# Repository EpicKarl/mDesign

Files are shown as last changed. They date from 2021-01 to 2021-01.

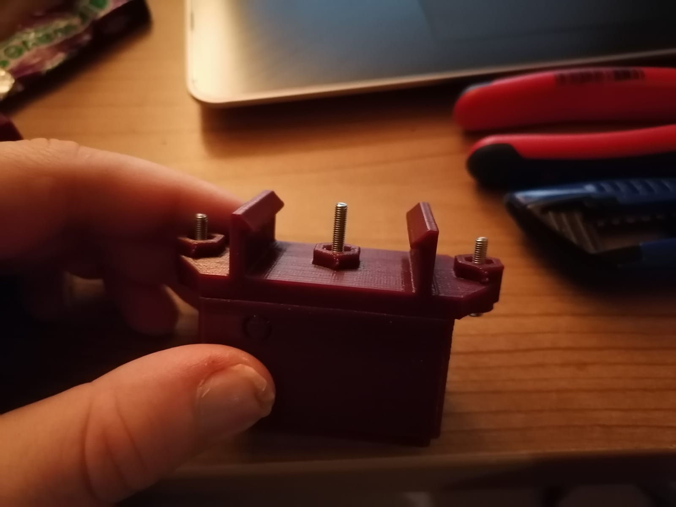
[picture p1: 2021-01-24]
Doku/HutschienengehaeuseCADDaten/ESP_Gehaeuse_Zusammenbau2.jpeg

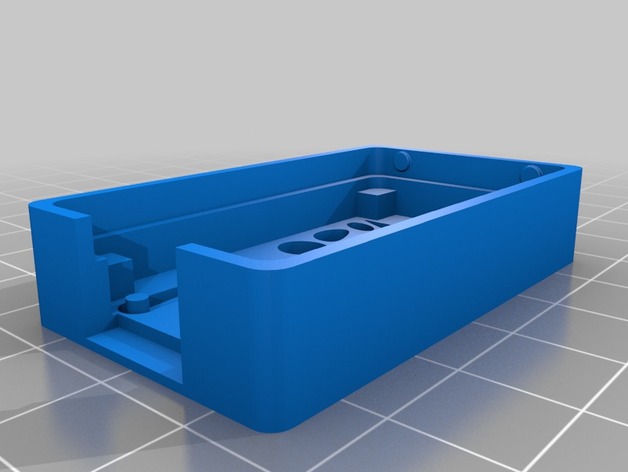
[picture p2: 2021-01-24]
Doku/HutschienengehaeuseCADDaten/ESP_Gehaeuse_Top.jpg

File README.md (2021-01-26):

# mDesign

# Aufspielen der Fernwartungsoftware auf den Node MCU ESP 8266:

1. Installiere VS Code
2. Installiere die Extension PlatformIO
3. Installiere den USB UART Treiber für den ESP 8266 aus dem Ordner "ESPDriver" oder lade ihn [hier](https://www.silabs.com/developers/usb-to-uart-bridge-vcp-drivers) herunter.
4. Workaround für die Treiberinstallation: Arduino IDE installieren

5. Clone Repository
6. VS Code starten Platform IO öffnen "Open Project" auswählen und den Ordner Fernwartung im Repo auswählen.
7. ESP mit PC verbinden
8. Bei COM Port Problemen [hier](https://docs.platformio.org/en/latest/projectconf/section_env_upload.html) nachschauen.
9. Vor dem Upload checken ob SOFTAP definiert und DEBUGMODE NICHT definiert sind.
10. Upload Button in Platform IO Project drücken. (blaue Leiste, Pfeil nach rechts)

# Debugging der Fernwartung

Für das Debuggen gibt es im Code verschiedene Präprozessoranweisungen. Dies ist nötig, da der ESP standardmäßig nur einen Hardware Serial Port besitzt. Beachte Hinweise im Code! Während ein PC an dem ESP angeschlossen ist, können dem Controllino KEINE Befehle gesendet werden.

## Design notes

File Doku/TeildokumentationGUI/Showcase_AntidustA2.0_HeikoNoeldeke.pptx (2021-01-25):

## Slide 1

- Mechatronisches Design
- Team Fernwartung
- Hochschule für Angewandte Wissenschaften Hamburg
- 26.01.2021

- V 2.0

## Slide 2

- GUI

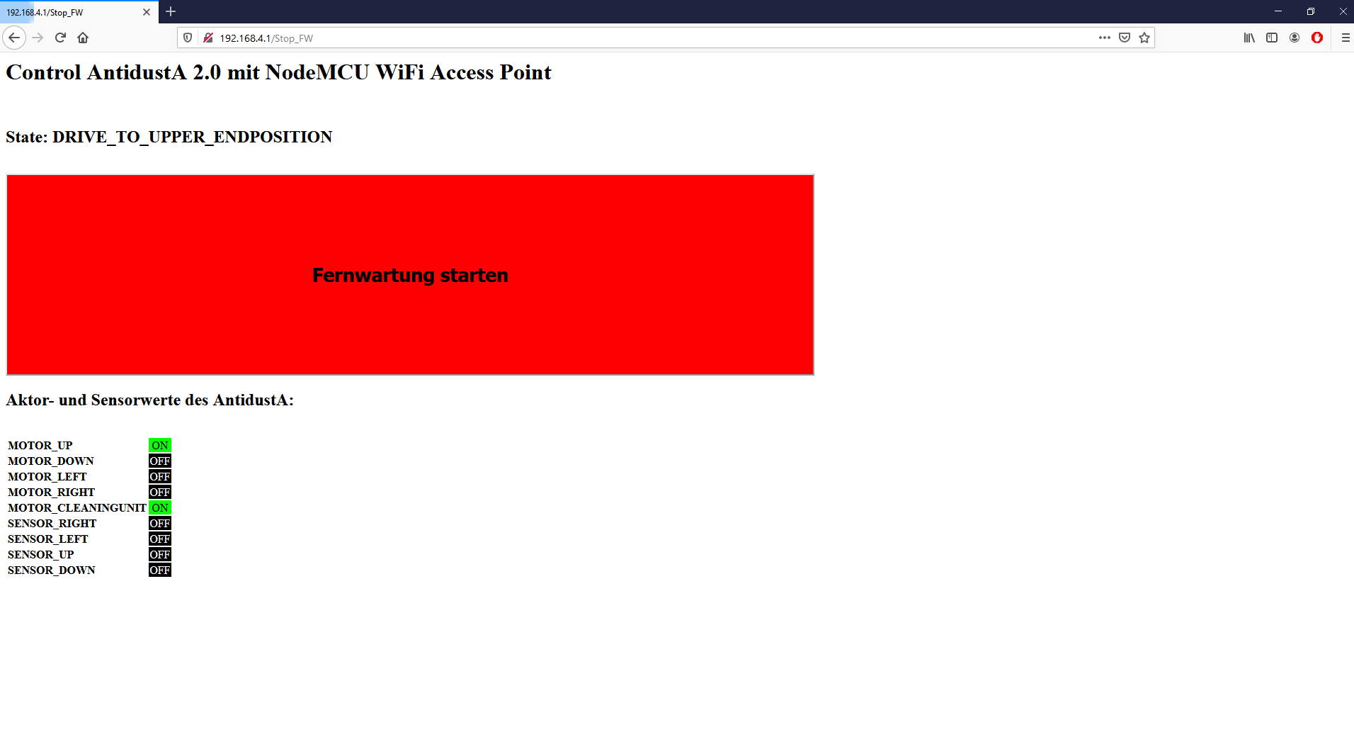
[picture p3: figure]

GUI verwenden:
- AntidustA einschalten
- Device mit WLAN „AntidustA_Control“ verbinden
- Passwort: AntidustA
- IP Adresse eingeben: 192.168.4.1
- GUI verwenden

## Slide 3

- Manueller gui Modus

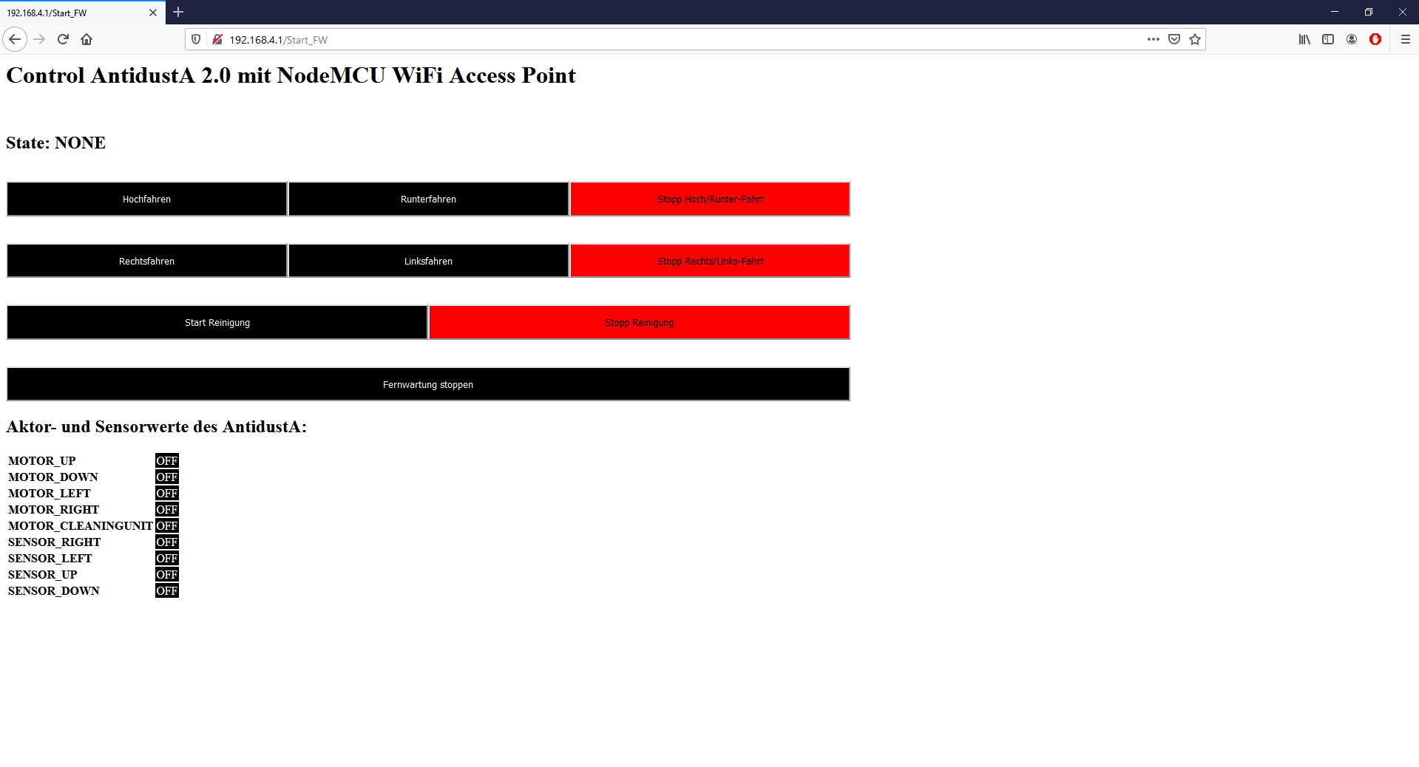
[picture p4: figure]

- Funktionalität:
- Hoch/Runter Fahrt
- Rechts/Links Fahrt
- Reinigung
- Immer nur EINE Funktionalität zeitgleich verwenden

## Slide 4

- Aktor- und sensorwerte

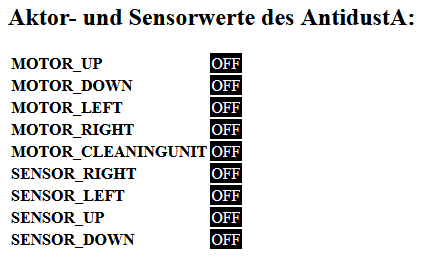
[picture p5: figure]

- Aktor- und Sensorwerte:
- Immer sichtbar
- Reagieren auf gesendete Werte vom Controllino Maxi
- Im folgenden Video: Mock-Up gibt Muster vor

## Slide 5

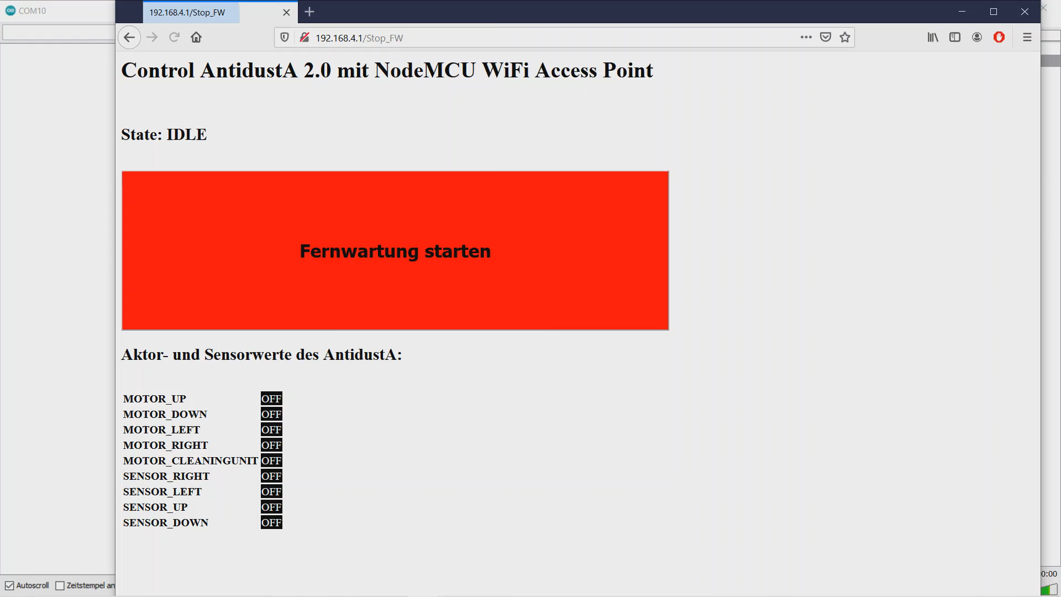
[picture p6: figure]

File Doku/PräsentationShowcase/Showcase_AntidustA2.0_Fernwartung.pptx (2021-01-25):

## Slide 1

- Mechatronisches Design
- Team Fernwartung
- Hochschule für Angewandte Wissenschaften Hamburg
- 26.01.2021

- V 2.0

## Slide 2

- Fernwartung

- Problemstellung:
- - Systeminformationen erhalten, ohne vor Ort zu sein
- - Steuerbefehle senden
- - Problemlösung aus der Ferne
- Lösung:
- - Einbau des WLAN-Moduls „NodeMCU“
- - Hosten eines Webservers auf dem Modul
- - Zugriff über Accesspoint oder bestehendes Netzwerk

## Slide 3

- Teilaufgaben

- Schnittstelle zum Controllino
- - Sensorabbild empfangen, Aktor-Abbild übertragen
- - Auswahl eines Kommunikationsprotokolls
- - Definition eines Datenrahmens
- - Codierung der Daten
- - Schreiben der Funktionen für das Empfangen der Sensor-Daten
- - Schreiben der Funktion für das Senden der Aktor-Daten
- - Entwickeln eines Testkonzepts
- Hosten des Webservers, erstellen einer GUI
- - Bereitstellen des Accesspoint/verbinden mit dem bestehenden Netzwerk
- - Hosten des Webservers
- - Entwicklung, Design und Testen der GUI
- - Verarbeitung der Nutzereingaben
- - Darstellung der Sensordaten

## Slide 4

- Schnittstelle zum Controllino - Entwurf

Wahl von UART als Kommunikationsprotokoll:

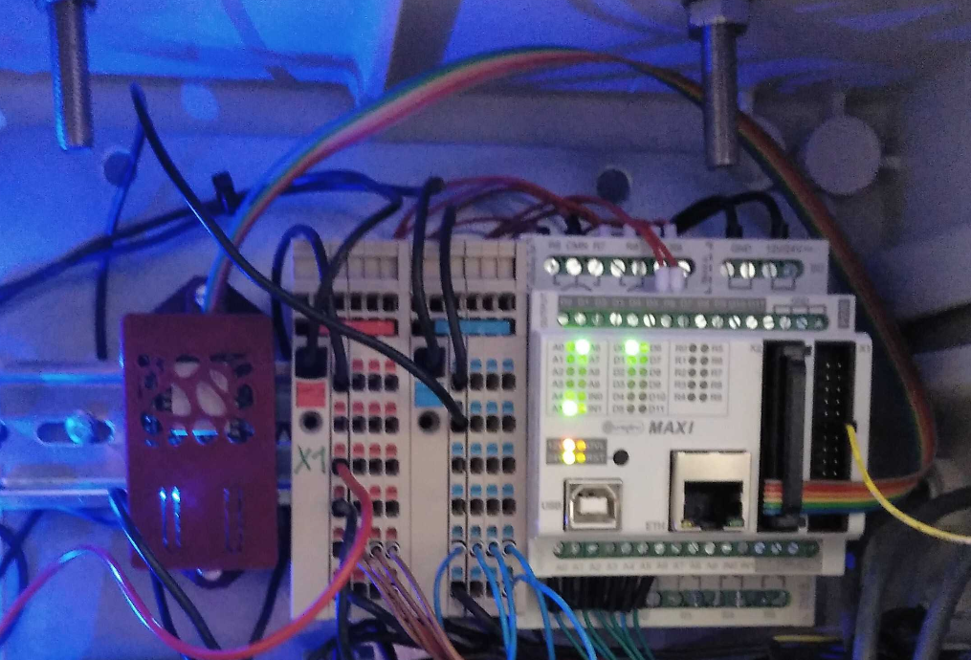
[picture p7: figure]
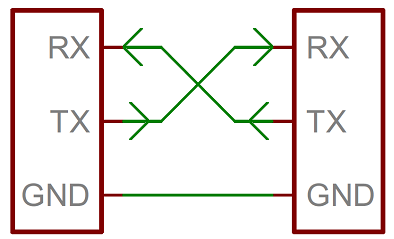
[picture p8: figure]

Telegramminhalt aus Sicht des NodeMCU:

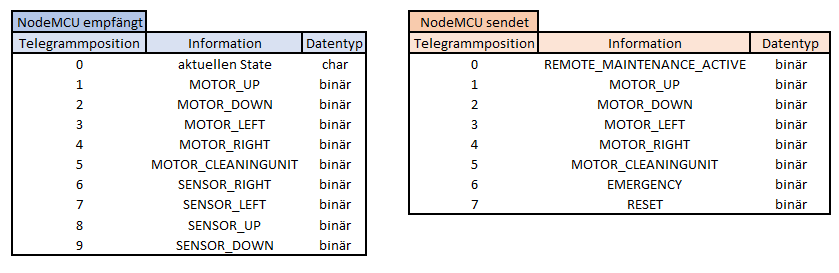
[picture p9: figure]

Codierung aller Systemzustände in Buchstaben A-L:

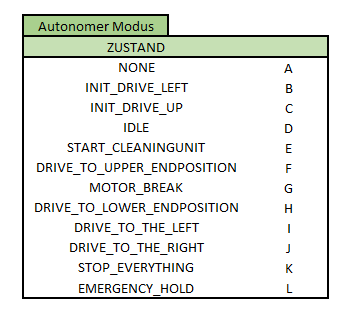
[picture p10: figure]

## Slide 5

- Schnittstelle zum Controllino - Lösungen, Test

- Funktionen für das Empfangen der Sensor-Daten
- Überprüft ob Daten zum Empfangen an der seriellen Schnittstelle anliegen
- Liest und interpretiert Daten zur weiteren Verwendung in Array ein

Funktion für das Senden der Aktor-Daten
- Sendet das im System für das Senden bereitgestellte Array an die serielle Schnittstelle

Test der Funktionen mittels Mock-Up
- Zusätzlicher Arduino simuliert das Verhalten des AntidustA während eines Reinigungsvorgangs
- Mock-Up liest Nutzereingaben aus der GUI und sendet entsprechende Reaktionen
- Das Testen der korrekten Übertagung und Interpretation der Daten wird somit ermöglicht

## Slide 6

- GUI


GUI verwenden:
- AntidustA einschalten
- Device mit WLAN „AntidustA_Control“ verbinden
- Passwort: AntidustA
- IP Adresse eingeben: 192.168.4.1
- GUI verwenden

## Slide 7

- Manueller gui Modus


- Funktionalität:
- Hoch/Runter Fahrt
- Rechts/Links Fahrt
- Reinigung
- Immer nur EINE Funktionalität zeitgleich verwenden

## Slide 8

- Aktor- und sensorwerte


- Aktor- und Sensorwerte:
- Immer sichtbar
- Reagieren auf gesendete Werte vom Controllino Maxi
- Im folgenden Video: Mock-Up gibt Muster vor

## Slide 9

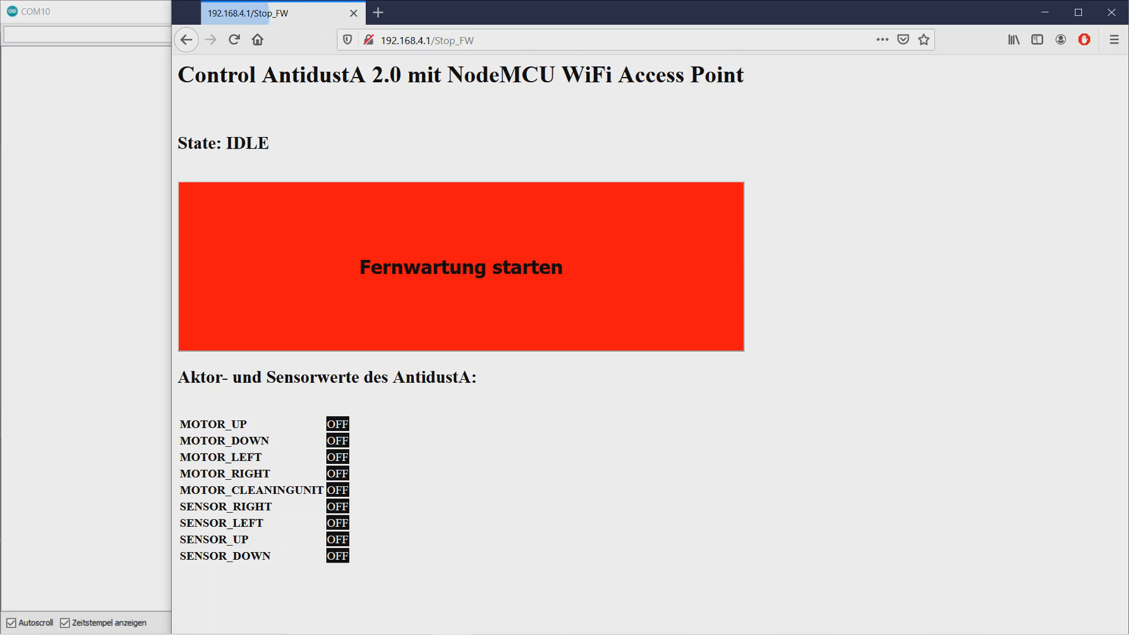
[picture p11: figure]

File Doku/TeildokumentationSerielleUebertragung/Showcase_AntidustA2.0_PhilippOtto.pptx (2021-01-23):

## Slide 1

- Mechatronisches Design
- Team X/Y
- Hochschule für Angewandte Wissenschaften Hamburg
- 26.01.2021

- V 2.0

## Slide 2

- verantwortete Systemelemente und Schnittstellen

- „Schnittstelle zum Arduino“
- Sensorabbild empfangen, Aktor-Abbild übertragen
- - Auswahl eines Kommunikationsprotokolls
- - Definition eines Datenrahmens
- - Codierung der Daten
- - Schreiben der Funktionen für das Empfangen der Sensor-Daten
- - Schreiben der Funktion für das Senden der Aktor-Daten

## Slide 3

- Entwurf – FMEA - Test

Wahl von UART als Kommunikationsprotokoll:


Telegramminhalt aus Sicht des NodeMCU:


Codierung aller Systemzustände in Buchstaben A-L:


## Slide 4

- Rückblick auf die bisherige und ausblick auf die weitere tätigkeit

- Funktionen für das Empfangen der Sensor-Daten
- Überprüft ob Daten zum Empfangen an der seriellen Schnittstelle anliegen
- Liest und interpretiert Daten zur weiteren Verwendung in Array ein

Funktion für das Senden der Aktor-Daten
- Sendet das im System für das Senden bereitgestellte Array an die serielle Schnittstelle

Test der Funktionen mittels Mock-Up
- Zusätzlicher Arduino simuliert das Verhalten des AntidustA während eines Reinigungsvorgangs
- Mock-Up liest Nutzereingaben aus der GUI und sendet entsprechende Reaktionen
- Das Testen der korrekten Übertagung und Interpretation der Daten wird somit ermöglicht

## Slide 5

- Fernwartungs-GUI

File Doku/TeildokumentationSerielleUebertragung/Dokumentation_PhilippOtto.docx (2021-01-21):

# Schnittstelle Arduino-Fernwartung

Der Datenaustausch zwischen Controllino-MAXI und NodeMCU wird mithilfe der seriellen Schnittstelle UART realisiert. Die hierfür in der Arduino-Bibliothek zur Verfügung stehenden Funktionen erleichtern die Realisierung einer solchen Übertragung.


Abbildung 1: Verschaltung zwischen Controllino-MAXI und NodeMCU

Um eine serielle Schnittstelle zwischen zwei Mikrocontrollern zu realisieren, ist es lediglich notwendig die RX und TX-Pins beider Controller gekreuzt sowie beide GND-Pins miteinander zu verbinden.

## Das Telegramm

Eine Datenübertragung erfordert ein gemeinsames Protokoll zwischen Sender und Empfänger. Da in diesem Fall Sender und Empfänger von zwei unterschiedlichen Teams bearbeitet werden ist eine gute Schnittstellen Koordination erforderlich.

Beide Seiten der Übertragung müssen auf der gleichen Baudrate kommunizieren, damit die übertragene Nachricht korrekt eingelesen werden kann.

Darüber hinaus ist es notwendig ein festen Telegramminhalt zu vereinbaren, um beim Einlesen der Nachricht eine Korrekte Interpretation der Daten durchführen zu können.

Aufgrund der statischen Interpretation der Werte ist eine konstante Länge der übertragenen Nachricht notwendig.


Abbildung 2: Übertragungsprotokoll aus Sicht des NodeMCU

Das Übertragen des aktuellen Systemzustandes stellt ein Problem dar. Systemintern wird der Zustand einem Integer Wert von 0-11 zugewiesen. Da dieser Zustand zwischen 1 und 2 Zeichen variiert, werden zu Zustande als ASCII-Zeichen anhand der gezeigten Tabelle interpretiert.


Abbildung 3: Codierung der empfangenen Zustände

Ein Ausblick auf eine mögliche Verbesserung der Übertragung wäre die Verwendung von Trennzeichen. Dadurch könnten zusammenhängende Nachrichten mit variierenden Längen besser interpretiert werden und eine fehlerhafte Übertragung wird leichter erkannt.

## Senden der Nutzereingaben

Die vom Nutzer an der GUI getätigten Eingaben werden Systemintern in einem Array aus acht Elementen gespeichert.

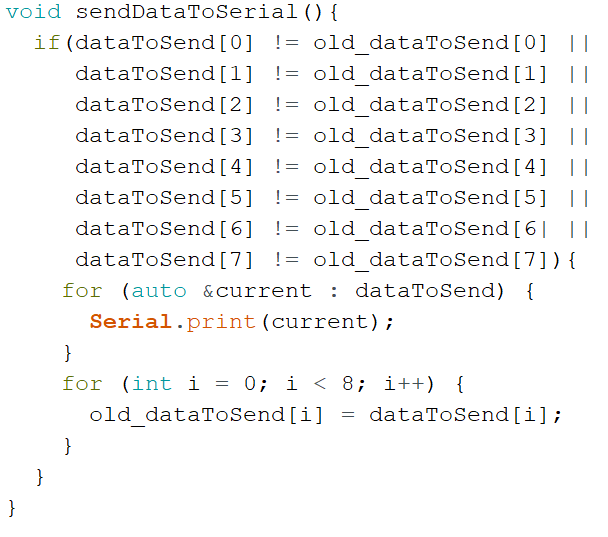
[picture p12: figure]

Abbildung 4: Funktion zur Datenübertragung an den Controllino-MAXI

Dieses Array wird nun überprüft, ob es sich im Vergleich zum letzten Systemtakt verändert hat. Ist dem der Fall, so wird durch das Array iteriert und mithilfe der Funktion Serial.print() werden die einzelnen Elemente des Arrays über den Seriellen Ausgang übertragen.

## Empfangen der Übertragung aus Controllino-MAXI

Eine Übertragung von Controllino-MAXI findet ebenfalls nur statt, wenn sich der Zustand eines der Telegrammelemente verändert. Beim Empfangen der Nachricht ist es also sinnvoll zunächst mit der Funktion Serial.available() zu überprüfen, ob auszulesende Daten am seriellen Eingang anliegen.

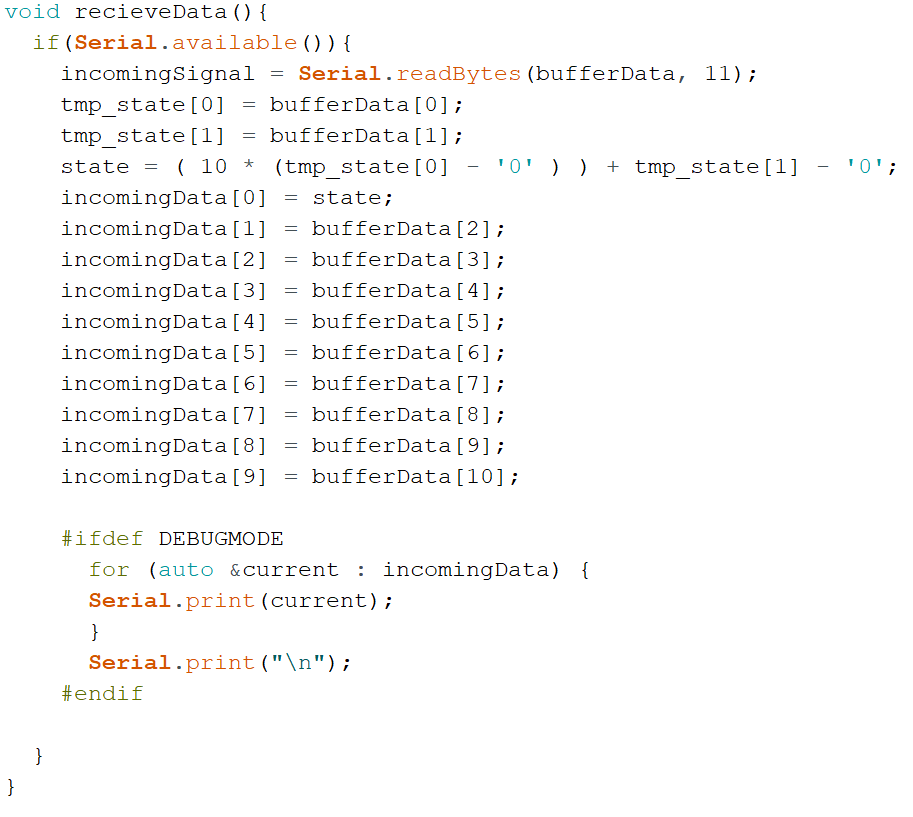
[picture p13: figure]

Abbildung 5: Funktion zum Empfangen der Daten von Controllino-MAXI

Liegen Daten am seriellen Eingang an, so werden diese zur Aufbereitung in einem Buffer gespeichert. Das erste eingelesene Element ist laut Telegrammvereinbarung immer ein Buchstabe. Dieser wird als ASCII-Zeichen übertragen. Bei der Interpretation der Empfangenen Nachricht müssen die ersten beiden Stellen des Arrays zunächst in ein Integer Wert gewandelt werden, um diesen als Char darstellen zu können.

Im Anschluss daran, können die eingelesenen Werte einem Array zugewiesen werden, welches zur weiteren Darstellung in der GUI verwendet wird.

## Testen der Funktionen

Das Testen der Funktion von GUI und Übertragung kann mithilfe eine Mock-Ups des AntidustA geschehen. Hierfür wird ein zusätzlicher Arduino verwendet, der nach einem vordefinierten Ablauf das Verhalten des AntidustA während eines Reinigungsvorgangs simuliert.

Dafür wird die Übertragene Nachricht unter Bezugnahme des Hardwareverhaltens in festgelegten Abständen variiert. In der GUI kann so der simulierte Reinigungsvorgang beobachtet werden.

Wechselt man in den manuellen Betrieb des AntidustA, so regiert der Mock-Up auf Nutzereingaben nach vorher definierten Verhaltensweisen.

Auf diese Weise kann die korrekte Funktion der GUI und das Übertragen von Daten an und von dem Controllino-MAXI getestet werden, ohne dass eine Hardware vorhanden ist.

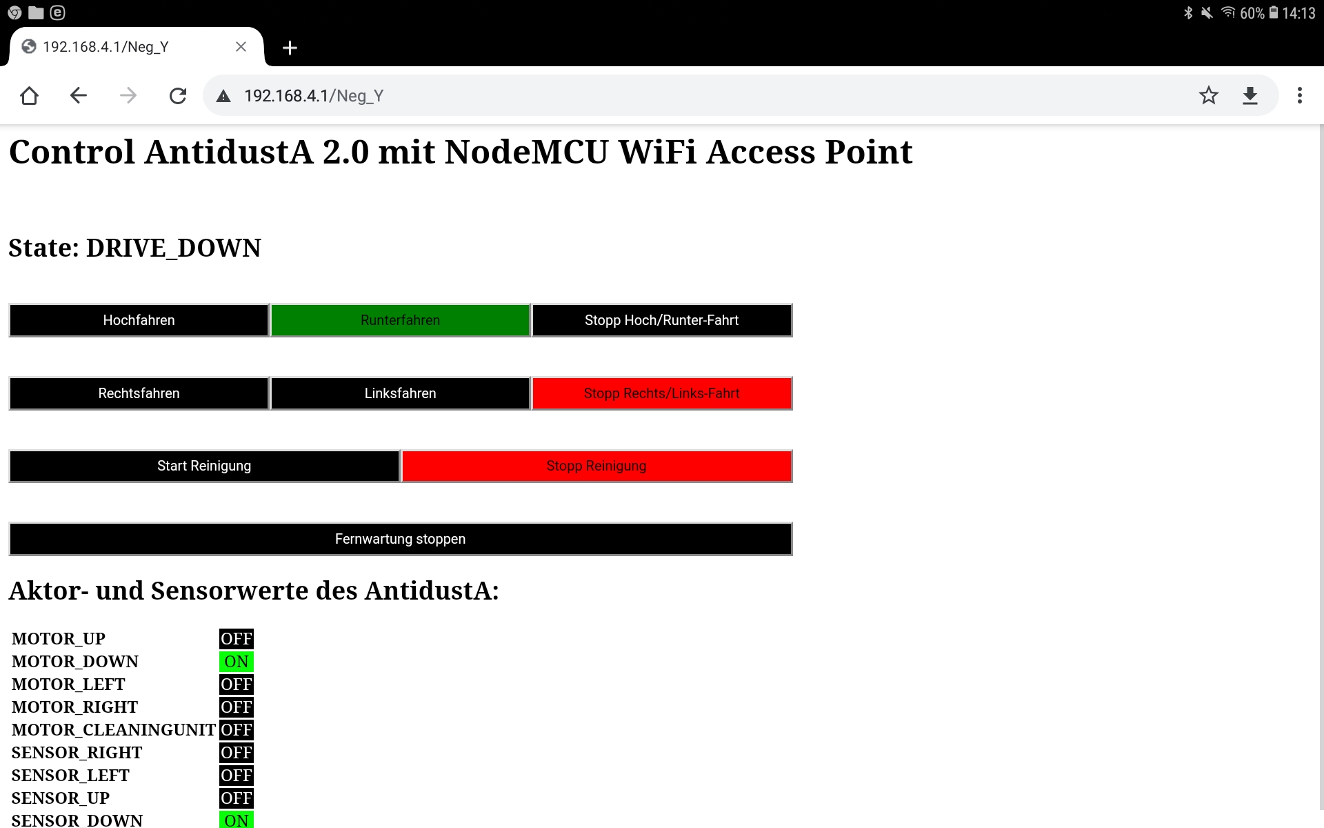
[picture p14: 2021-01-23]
Doku/TeildokumentationGUI/Bild_2.jpg

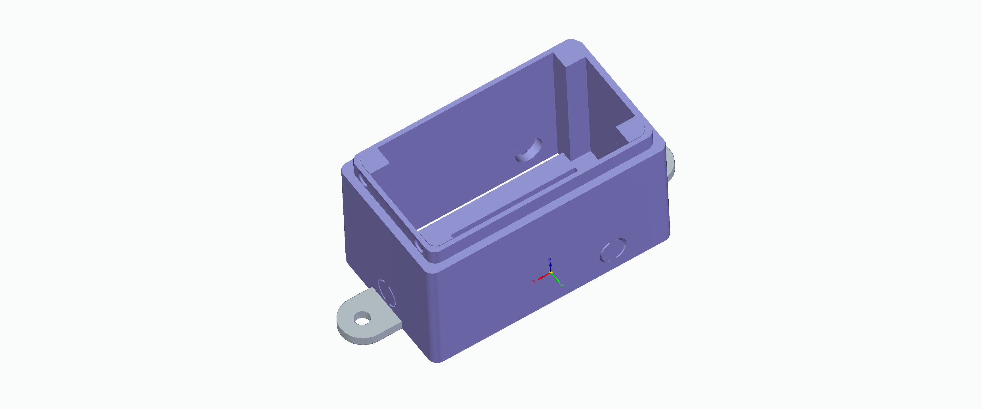
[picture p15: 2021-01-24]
Doku/HutschienengehaeuseCADDaten/ESP_BoxButtom.jpg

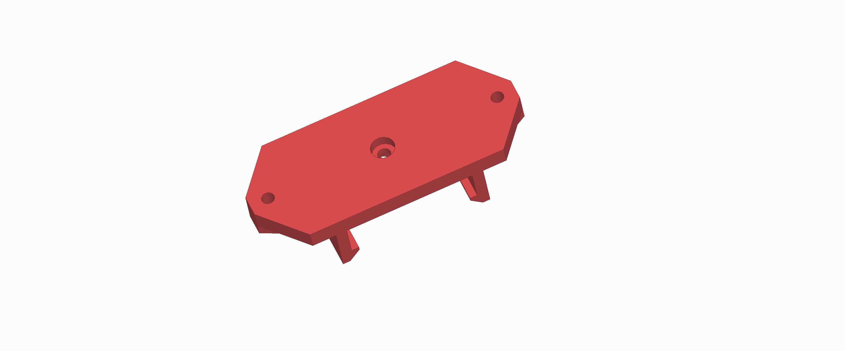
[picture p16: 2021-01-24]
Doku/HutschienengehaeuseCADDaten/ESP_AdapterBild2.jpg

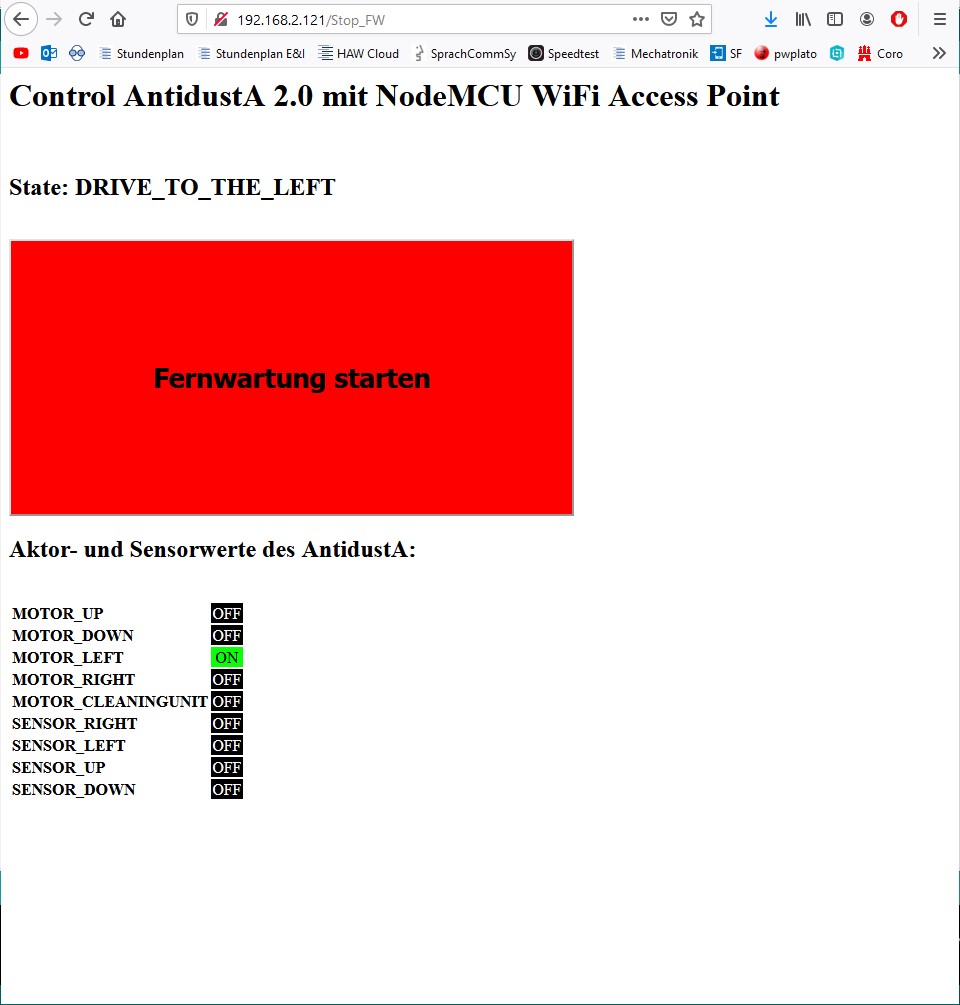
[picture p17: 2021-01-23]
Doku/TeildokumentationGUI/GUI_Automatik.jpg

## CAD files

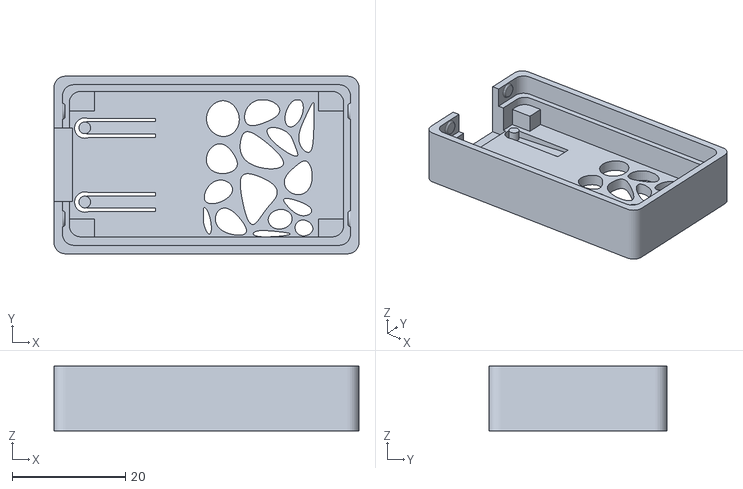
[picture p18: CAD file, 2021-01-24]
Doku/HutschienengehaeuseCADDaten/case_top_v4.stl
53.9 x 31.4 x 11.4

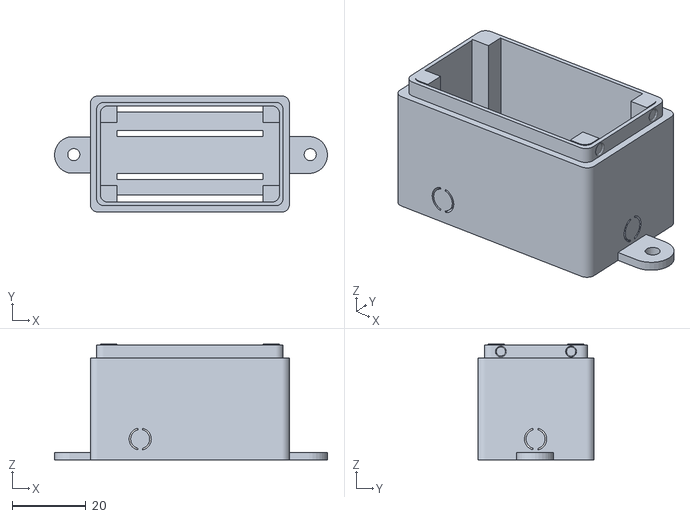
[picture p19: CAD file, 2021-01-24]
Doku/HutschienengehaeuseCADDaten/case_bottom_v3.stl
73.9 x 31.4 x 31.3

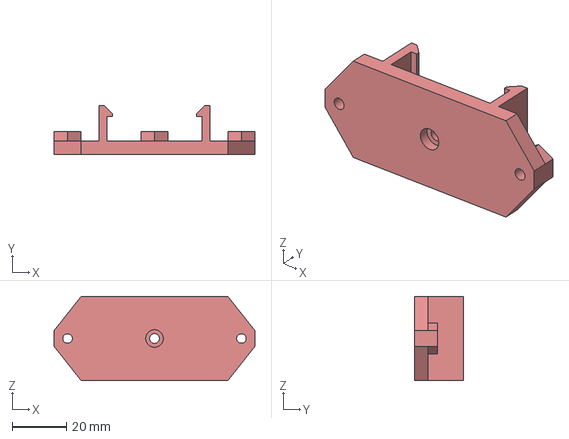
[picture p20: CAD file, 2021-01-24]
Doku/HutschienengehaeuseCADDaten/ESP_Adapter.stp
74.0 x 18.0 x 31.0 mm

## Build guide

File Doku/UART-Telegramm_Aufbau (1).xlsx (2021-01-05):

 |  |  |  | Vorschlag für zu erhaltenden Daten
Arduino Sendet |  |  |  | Arduino Empfängt
Telegrammposition | Inforamtion | Datentyp |  | Telegrammposition | Inforamtion | Datentyp
0 | aktuellen State | char |  | 0 | REMOTE_MAINTENANCE_ACTIVE | binär
1 | MOTOR_UP | binär |  | 1 | MOTOR_UP | binär
2 | MOTOR_DOWN | binär |  | 2 | MOTOR_DOWN | binär
3 | MOTOR_LEFT | binär |  | 3 | MOTOR_LEFT | binär
4 | MOTOR_RIGHT | binär |  | 4 | MOTOR_RIGHT | binär
5 | MOTOR_CLEANINGUNIT | binär |  | 5 | MOTOR_CLEANINGUNIT | binär
6 | SENSOR_RIGHT | binär |  | 6 | EMERGENCY | binär
7 | SENSOR_LEFT | binär |  | 7 | RESET | binär
8 | SENSOR_UP | binär
9 | SENSOR_DOWN | binär
MANUAL |  |  | AUTONOMOUS
ZUSTAND |  |  | ZUSTAND
NONE | A |  | NONE |  | A
DRIVE_UP | B |  | INIT_DRIVE_LEFT |  | B
DRIVE_DOWN | C |  | INIT_DRIVE_UP |  | C
DRIVE_LEFT | D |  | IDLE |  | D
DRIVE_RIGHT | E |  | START_CLEANINGUNIT |  | E
CLEANINGUNIT | F |  | DRIVE_TO_UPPER_ENDPOSITION |  | F
MOTOR_BREAK | G |  | MOTOR_BREAK |  | G
EMERGENCY_HOLD | H |  | DRIVE_TO_LOWER_ENDPOSITION |  | H
 |  |  | DRIVE_TO_THE_LEFT |  | I
 |  |  | DRIVE_TO_THE_RIGHT |  | J
 |  |  | STOP_EVERYTHING |  | K
 |  |  | EMERGENCY_HOLD |  | L

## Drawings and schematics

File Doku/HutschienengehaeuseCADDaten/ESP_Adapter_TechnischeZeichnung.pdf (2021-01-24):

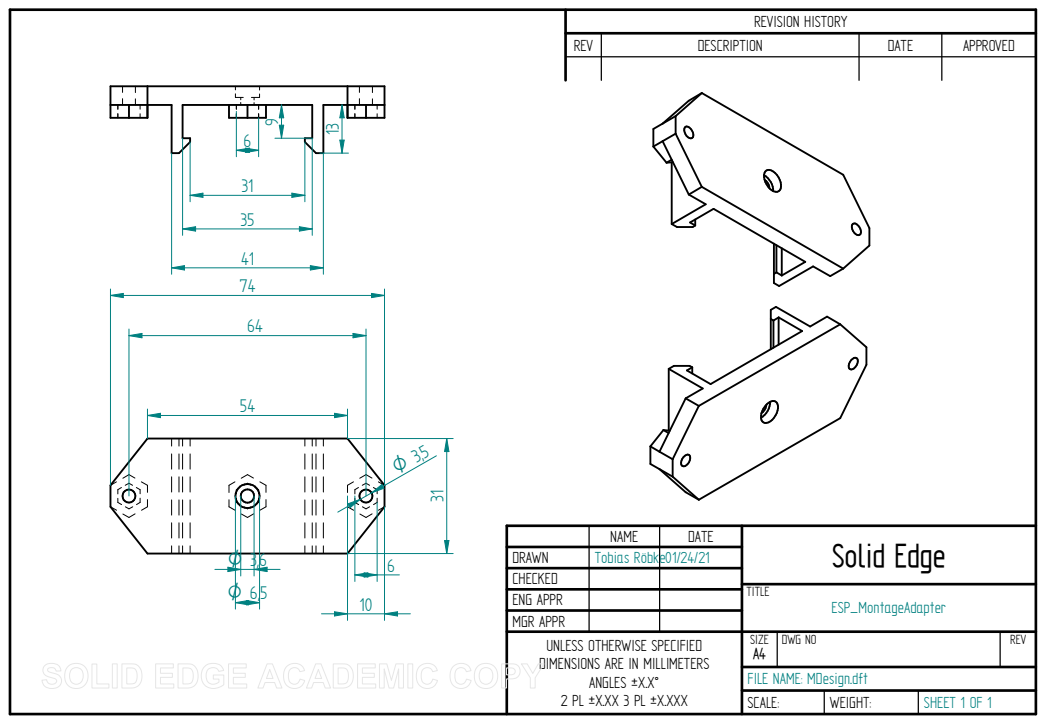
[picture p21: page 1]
TITLE; ESP_MontageAdapter; SCALE:; WEIGHT:; SHEET 1 OF 1

REVISION HISTORY

REV | DESCRIPTION | DATE | APPROVED

NAME | DATE | Solid Edge

DRAWN | Tobias Röbke | 01/24/21
CHECKED
ENG APPR
MGR APPR
UNLESS OTHERWISE SPECIFIED DIMENSIONS ARE IN MILLIMETERS ANGLES ±X.X° 2 PL ±X.XX 3 PL ±X.XXX | SIZE A4 | DWG NO | REV

FILE NAME: MDesign.dft

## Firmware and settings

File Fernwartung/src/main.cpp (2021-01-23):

// Version 1.5
/*
Ein Emergency Button aus der Ferne ist gefählich, da wir nicht sicherstellen können, dass die Verbidnung zu jeden Zeitpunkt zuverläsig ist, daher nicht zu empfehlen ---> Überarbeitung
Reset Button unnötog, wenn Emergency Button nicht implementiert
*/

//#define DEBUGMODE
//#define HOMENETWORK
#define SOFTAP

#include <Arduino.h>
#include <ESP8266WebServer.h> 
#include <ESP8266WiFi.h>
#include <WiFiClient.h>


// Receiving Data by Philipp Otto ------------------------------------------------------------------------------
byte bufferData[11] = {};
char incomingData[10] = {};

byte dataToSend[6] = {};
byte old_dataToSend[6] = {};

char tmp_state[2] = {};

byte incomingSignal;
char state;
void recieveData(){
  //Serial.setTimeout(100);
  if(Serial.available()){
    incomingSignal = Serial.readBytes(bufferData, 11);

    tmp_state[0] = bufferData[0];
    tmp_state[1] = bufferData[1];
    
    state = ( 10 * (tmp_state[0] - '0' ) ) + tmp_state[1] - '0'; // own atoi()

    incomingData[0] = state;            //Zuweisungen in char Array für Server
    incomingData[1] = bufferData[2];
    incomingData[2] = bufferData[3];
    incomingData[3] = bufferData[4];
    incomingData[4] = bufferData[5];
    incomingData[5] = bufferData[6];
    incomingData[6] = bufferData[7];
    incomingData[7] = bufferData[8];
    incomingData[8] = bufferData[9];
    incomingData[9] = bufferData[10];

    #ifdef DEBUGMODE
      for (auto &current : incomingData) {  //Konsolenausgabe zum Debuggen
      Serial.print(current);              
      }
      Serial.print("\n");
    #endif

  }
}

void sendDataToSerial(){
  if(dataToSend[0] != old_dataToSend[0] || //sendet nur wenn sich irgendwas ändert
     dataToSend[1] != old_dataToSend[1] || 
     dataToSend[2] != old_dataToSend[2] ||
     dataToSend[3] != old_dataToSend[3] ||
     dataToSend[4] != old_dataToSend[4] ||
     dataToSend[5] != old_dataToSend[5]){
    for (auto &current : dataToSend) { 
      Serial.print(current);
    }
    for (int i = 0; i < 6; i++) {
      old_dataToSend[i] = dataToSend[i];
    }
  }
}
//-------------------------------------------------------------------------------------------------------------------------------------------------------------------------------------------

//Instanz des ESP8266WebServers
ESP8266WebServer server(80);

// Make a wifi name and password as access points
#ifdef HOMENETWORK
  const char *ssid = "********";
  const char *password = "*******";
#endif
  
#ifdef SOFTAP
  const char *ssid = "AntidustA_Control";
  const char *password = "AntidustA";
#endif
// ------------------------------------Declare constants to make the page to be visited.----------------------------
/*const String HtmlHtml = "<html><head>"
"<meta name=\"viewport\" content=\"width=device-width, initial-scale=1\" /></head>";*/
const String HtmlHtml = "<html><head>"
"<meta name=\"viewport\" content=\"width=device-width, initial-scale=1\" />"
"<meta http-equiv=\"REFRESH\" content=\"1\"/>"
"</head>";
const String HtmlTitle = "<h1>Control AntidustA 2.0 mit NodeMCU WiFi Access Point</h1><br/>";
const String HtmlHtmlClose = "</html>";
// -----------------------------------------------------------------------------------------------------------------
void response(){
  String htmlRes = HtmlHtml + HtmlTitle;
  if(dataToSend[0] == 0){
    //STATE
    switch (incomingData[0])
    {
      case 'A':
        htmlRes += "<h2>State: NONE</h2><br/>";
        break;
      case 'B':
        htmlRes += "<h2>State: INIT_DRIVE_LEFT</h2><br/>";
        break;
      case 'C':
        htmlRes += "<h2>State: INIT_DRIVE_UP</h2><br/>";
        break;
      case 'D':
        htmlRes += "<h2>State: IDLE</h2><br/>";
        break;
      case 'E':
        htmlRes += "<h2>State: START_CLEANING</h2><br/>";
        break;
      case 'F':
        htmlRes += "<h2>State: DRIVE_TO_UPPER_ENDPOSITION</h2><br/>";
        break;
      case 'G':
        htmlRes += "<h2>State: MOTOR_BREAK</h2><br/>";
        break;
      case 'H':
        htmlRes += "<h2>State: DRIVE_TO_LOWER_ENDPOSITION</h2><br/>";
        break;
      case 'I':
        htmlRes += "<h2>State: DRIVE_TO_THE_LEFT</h2><br/>";
        break;
      case 'J':
        htmlRes += "<h2>State: DRIVE_TO_THE_RIGHT</h2><br/>";
        break;
      case 'K':
        htmlRes += "<h2>State: STOP_EVERYTHING</h2><br/>";
        break;
      case 'L':
        htmlRes += "<h2>State: EMERGENCY_HOLD</h2><br/>";
        break;
      default:
        htmlRes += "<h2><font style=\"color:red\">FSM IST IN KEINEM DEFINIERTEN STATE! KONTROLLE DES SYSTEMS ERFORDERLICH!</font></h2><br/>";
        break;
    }
    //Fernwarung Starten
    htmlRes += "<a href=\"Start_FW\"><button style=\"background-color:red;color:black;width:60%;height:30%;\"><h1>Fernwartung starten</h1></button></a>";
    //Aktor und Sensorwerte
    htmlRes += "<h2>Aktor- und Sensorwerte des AntidustA:</h2><br/>";
    
    htmlRes += "<table>";
    
    if(incomingData[1] == '1'){
      htmlRes += "<tr> <td> <b>MOTOR_UP</b> </td> <td style=\"background-color:#08FF08;color:#000000\"align=center>ON</td> </tr>";
    }
    if(incomingData[1] == '0'){
      htmlRes += "<tr> <td> <b>MOTOR_UP</b> </td> <td style=\"background-color:#000000;color:white;\"align=center>OFF</td> </tr>";
    }
    
    if(incomingData[2] == '1'){
      htmlRes += "<tr> <td> <b>MOTOR_DOWN</b> </td> <td style=\"background-color:#08FF08;color:#000000\"align=center>ON</td> </tr>";
    }
    if(incomingData[2] == '0'){
      htmlRes += "<tr> <td> <b>MOTOR_DOWN</b> </td> <td style=\"background-color:#000000;color:white\"align=center>OFF</td> </tr>";
    }
    
    if(incomingData[3] == '1'){
      htmlRes += "<tr> <td> <b>MOTOR_LEFT</b </td> <td style=\"background-color:#08FF08;color:#000000\"align=center>ON</td> </tr>";
    }
    if(incomingData[3] == '0'){
      htmlRes += "<tr> <td> <b>MOTOR_LEFT</b> </td> <td style=\"background-color:#000000;color:white\"align=center>OFF</td> </tr>";
    }

    if(incomingData[4] == '1'){
      htmlRes += "<tr> <td> <b>MOTOR_RIGHT</b> </td> <td style=\"background-color:#08FF08;color:#000000\"align=center>ON</td> </tr>";
    }
    if(incomingData[4] == '0'){
      htmlRes += "<tr> <td> <b>MOTOR_RIGHT</b> </td> <td style=\"background-color:#000000;color:white\"align=center>OFF</td> </tr>";
    }

    if(incomingData[5] == '1'){
      htmlRes += "<tr> <td> <b>MOTOR_CLEANINGUNIT</b> </td> <td style=\"background-color:#08FF08;color:#000000\"align=center>ON</td> </tr>";
    }
    if(incomingData[5] == '0'){
      htmlRes += "<tr> <td> <b>MOTOR_CLEANINGUNIT</b> </td> <td style=\"background-color:#000000;color:white\"align=center>OFF</td> </tr>";
    }

    if(incomingData[6] == '1'){
      htmlRes += "<tr> <td> <b>SENSOR_RIGHT</b> </td> <td style=\"background-color:#08FF08;color:#000000\"align=center>ON</td> </tr>";
    }
    if(incomingData[6] == '0'){
      htmlRes += "<tr> <td> <b>SENSOR_RIGHT</b> </td> <td style=\"background-color:#000000;color:white\"align=center>OFF</td> </tr>";
    }

    if(incomingData[7] == '1'){
      htmlRes += "<tr> <td> <b>SENSOR_LEFT</b> </td> <td style=\"background-color:#08FF08;color:#000000\"align=center>ON</td> </tr>";
    }
    if(incomingData[7] == '0'){
      htmlRes += "<tr> <td> <b>SENSOR_LEFT</b> </td> <td style=\"background-color:#000000;color:white\"align=center>OFF</td> </tr>";
    }

    if(incomingData[8] == '1'){
      htmlRes += "<tr> <td> <b>SENSOR_UP</b> </td> <td style=\"background-color:#08FF08;color:#000000\"align=center>ON</td> </tr>";
    }
    if(incomingData[8] == '0'){
      htmlRes += "<tr> <td> <b>SENSOR_UP</b> </td> <td style=\"background-color:#000000;color:white\"align=center>OFF</td> </tr>";
    }

    if(incomingData[9] == '1'){
      htmlRes += "<tr> <td> <b>SENSOR_DOWN</b> </td> <td style=\"background-color:#08FF08;color:#000000\"align=center>ON</td> </tr>";
    }
    if(incomingData[9] == '0'){
      htmlRes += "<tr> <td> <b>SENSOR_DOWN</b> </td> <td style=\"background-color:#000000;color:white\"align=center>OFF</td> </tr>";
    }

    htmlRes += "</table>";

    htmlRes += HtmlHtmlClose;
    server.send(200, "text/html", htmlRes); 
  }
  else {
    //STATE
    switch (incomingData[0])
    {
      case 'A':
        htmlRes += "<h2>State: <font color:red>NONE</font></h2><br/>";
        break;
      case 'B':
        htmlRes += "<h2>State: DRIVE_UP</h2><br/>";
        break;
      case 'C':
        htmlRes += "<h2>State: DRIVE_DOWN</h2><br/>";
        break;
      case 'D':
        htmlRes += "<h2>State: DRIVE_LEFT</h2><br/>";
        break;
      case 'E':
        htmlRes += "<h2>State: DRIVE_RIGHT</h2><br/>";
        break;
      case 'F':
        htmlRes += "<h2>State: CLEANINGUNIT</h2><br/>";
        break;
      case 'G':
        htmlRes += "<h2>State: MOTOR_BREAK</h2><br/>";
        break;
      case 'H':
        htmlRes += "<h2>State: EMERGENCY_HOLD</h2><br/>";
        break;
      default:
        htmlRes += "<h2><font style=\"color:red\">FSM IST IN KEINEM DEFINIERTEN STATE! KONTROLLE DES SYSTEMS ERFORDERLICH!</font></h2><br/>"; 
        break;
    }
    //Y Drive Buttons
    if(dataToSend[1] == 1){
      htmlRes += 
        "<a href=\"Pos_Y\"><button style=\"background-color:green;color:black;width:20%;height:5%;\">Hochfahren </button></a>"
        "<a href=\"Neg_Y\"><button style=\"background-color:black;color:white;width:20%;height:5%;\">Runterfahren </button></a>"
        "<a href=\"SY\"><button style=\"background-color:black;color:white;width:20%;height:5%;\">Stopp Hoch/Runter-Fahrt </button></a><br/><br/><br/>";
    }
    else if(dataToSend[2] == 1){
      htmlRes += 
        "<a href=\"Pos_Y\"><button style=\"background-color:black;color:white;width:20%;height:5%;\">Hochfahren </button></a>"
        "<a href=\"Neg_Y\"><button style=\"background-color:green;color:black;width:20%;height:5%;\">Runterfahren </button></a>"
        "<a href=\"SY\"><button style=\"background-color:black;color:white;width:20%;height:5%;\">Stopp Hoch/Runter-Fahrt </button></a><br/><br/><br/>";
    } else {
      htmlRes += 
        "<a href=\"Pos_Y\"><button style=\"background-color:black;color:white;width:20%;height:5%;\">Hochfahren </button></a>"
        "<a href=\"Neg_Y\"><button style=\"background-color:black;color:white;width:20%;height:5%;\">Runterfahren </button></a>"
        "<a href=\"SY\"><button style=\"background-color:red;color:black;width:20%;height:5%;\">Stopp Hoch/Runter-Fahrt </button></a><br/><br/><br/>";
    }
    // X Drive Buttons
    if(dataToSend[3] == 1){
      htmlRes += 
        "<a href=\"Pos_X\"><button style=\"background-color:green;color:black;width:20%;height:5%;\">Rechtsfahren </button></a>"
        "<a href=\"Neg_X\"><button style=\"background-color:black;color:white;width:20%;height:5%;\">Linksfahren </button></a>"
        "<a href=\"SX\"><button style=\"background-color:black;color:white;width:20%;height:5%;\">Stopp Rechts/Links-Fahrt </button></a><br/><br/><br/>";
    }
    else if(dataToSend[4] == 1){
      htmlRes += 
        "<a href=\"Pos_X\"><button style=\"background-color:black;color:white;width:20%;height:5%;\">Rechtsfahren </button></a>"
        "<a href=\"Neg_X\"><button style=\"background-color:green;color:black;width:20%;height:5%;\">Linksfahren </button></a>"
        "<a href=\"SX\"><button style=\"background-color:black;color:white;width:20%;height:5%;\">Stopp Rechts/Links-Fahrt </button></a><br/><br/><br/>";
    } else {
      htmlRes += 
        "<a href=\"Pos_X\"><button style=\"background-color:black;color:white;width:20%;height:5%;\">Rechtsfahren </button></a>"
        "<a href=\"Neg_X\"><button style=\"background-color:black;color:white;width:20%;height:5%;\">Linksfahren </button></a>"
        "<a href=\"SX\"><button style=\"background-color:red;color:black;width:20%;height:5%;\">Stopp Rechts/Links-Fahrt </button></a><br/><br/><br/>";
    }

    
    //Cleaning Buttons
    if(dataToSend[5] == 1){
      htmlRes += 
        "<a href=\"Start_Cleaning\"><button style=\"background-color:green;color:black;width:30%;height:5%;\">Start Reinigung</button></a>"
        "<a href=\"Stop_Cleaning\"><button style=\"background-color:black;color:white;width:30%;height:5%;\">Stopp Reinigung</button></a><br/><br/><br/>";
    } else
    {
      htmlRes += 
        "<a href=\"Start_Cleaning\"><button style=\"background-color:black;color:white;width:30%;height:5%;\">Start Reinigung</button></a>"
        "<a href=\"Stop_Cleaning\"><button style=\"background-color:red;color:black;width:30%;height:5%;\">Stopp Reinigung</button></a><br/><br/><br/>";
    }

    //Fernwartung Stoppen Button
    htmlRes += "<a href=\"Stop_FW\"><button style=\"background-color:black;color:white;width:60%;height:5%;\">Fernwartung stoppen</button></a>";
    
    //Aktor und Sensorwerte
    htmlRes += "<h2>Aktor- und Sensorwerte des AntidustA:</h2>";
    
    htmlRes += "<table>";
    
    if(incomingData[1] == '1'){
      htmlRes += "<tr> <td> <b>MOTOR_UP</b> </td> <td style=\"background-color:#08FF08;color:#000000\"align=center>ON</td> </tr>";
    }
    if(incomingData[1] == '0'){
      htmlRes += "<tr> <td> <b>MOTOR_UP</b> </td> <td style=\"background-color:#000000;color:white;\"align=center>OFF</td> </tr>";
    }
    
    if(incomingData[2] == '1'){
      htmlRes += "<tr> <td> <b>MOTOR_DOWN</b> </td> <td style=\"background-color:#08FF08;color:#000000\"align=center>ON</td> </tr>";
    }
    if(incomingData[2] == '0'){
      htmlRes += "<tr> <td> <b>MOTOR_DOWN</b> </td> <td style=\"background-color:#000000;color:white\"align=center>OFF</td> </tr>";
    }
    
    if(incomingData[3] == '1'){
      htmlRes += "<tr> <td> <b>MOTOR_LEFT</b </td> <td style=\"background-color:#08FF08;color:#000000\"align=center>ON</td> </tr>";
    }
    if(incomingData[3] == '0'){
      htmlRes += "<tr> <td> <b>MOTOR_LEFT</b> </td> <td style=\"background-color:#000000;color:white\"align=center>OFF</td> </tr>";
    }

    if(incomingData[4] == '1'){
      htmlRes += "<tr> <td> <b>MOTOR_RIGHT</b> </td> <td style=\"background-color:#08FF08;color:#000000\"align=center>ON</td> </tr>";
    }
    if(incomingData[4] == '0'){
      htmlRes += "<tr> <td> <b>MOTOR_RIGHT</b> </td> <td style=\"background-color:#000000;color:white\"align=center>OFF</td> </tr>";
    }

    if(incomingData[5] == '1'){
      htmlRes += "<tr> <td> <b>MOTOR_CLEANINGUNIT</b> </td> <td style=\"background-color:#08FF08;color:#000000\"align=center>ON</td> </tr>";
    }
    if(incomingData[5] == '0'){
      htmlRes += "<tr> <td> <b>MOTOR_CLEANINGUNIT</b> </td> <td style=\"background-color:#000000;color:white\"align=center>OFF</td> </tr>";
    }

    if(incomingData[6] == '1'){
      htmlRes += "<tr> <td> <b>SENSOR_RIGHT</b> </td> <td style=\"background-color:#08FF08;color:#000000\"align=center>ON</td> </tr>";
    }
    if(incomingData[6] == '0'){
      htmlRes += "<tr> <td> <b>SENSOR_RIGHT</b> </td> <td style=\"background-color:#000000;color:white\"align=center>OFF</td> </tr>";
    }

    if(incomingData[7] == '1'){
      htmlRes += "<tr> <td> <b>SENSOR_LEFT</b> </td> <td style=\"background-color:#08FF08;color:#000000\"align=center>ON</td> </tr>";
    }
    if(incomingData[7] == '0'){
      htmlRes += "<tr> <td> <b>SENSOR_LEFT</b> </td> <td style=\"background-color:#000000;color:white\"align=center>OFF</td> </tr>";
    }

    if(incomingData[8] == '1'){
      htmlRes += "<tr> <td> <b>SENSOR_UP</b> </td> <td style=\"background-color:#08FF08;color:#000000\"align=center>ON</td> </tr>";
    }
    if(incomingData[8] == '0'){
      htmlRes += "<tr> <td> <b>SENSOR_UP</b> </td> <td style=\"background-color:#000000;color:white\"align=center>OFF</td> </tr>";
    }

    if(incomingData[9] == '1'){
      htmlRes += "<tr> <td> <b>SENSOR_DOWN</b> </td> <td style=\"background-color:#08FF08;color:#000000\"align=center>ON</td> </tr>";
    }
    if(incomingData[9] == '0'){
      htmlRes += "<tr> <td> <b>SENSOR_DOWN</b> </td> <td style=\"background-color:#000000;color:white\"align=center>OFF</td> </tr>";
    }

    htmlRes += "</table>";

    htmlRes += HtmlHtmlClose;
    server.send(200, "text/html", htmlRes);
  }
}
void positiveYDrive(){
  dataToSend[1] = 1;
  dataToSend[2] = 0;
  response();
}
void negativeYDrive(){
  dataToSend[1] = 0;
  dataToSend[2] = 1;
  response();
}
void stopYDrive(){
  dataToSend[1] = 0;
  dataToSend[2] = 0;
  response();
}
void positiveXDrive(){
  dataToSend[3] = 1;
  dataToSend[4] = 0;
  response();
}
void negativeXDrive(){
  dataToSend[3] = 0;
  dataToSend[4] = 1;
  response();
}
void stopXDrive(){
  dataToSend[3] = 0;
  dataToSend[4] = 0;
  response();
}
void startCleaning(){
  dataToSend[5] = 1;
  response();
}
void stopCleaning(){
  dataToSend[5] = 0;
  response();
}
void startFW(){
  dataToSend[0] = 1;
  response();
}
void stopFW(){
  dataToSend[0] = 0;
  dataToSend[1] = 0;
  dataToSend[2] = 0;
  dataToSend[3] = 0;
  dataToSend[4] = 0;
  dataToSend[5] = 0;
  response();
}

// STANDARD ARDUINO CODE AB HIER --------------------------------------------------------------------------------------------------------------------------------
void setup() {
  Serial.begin(9600);
  // Status LED
  pinMode(D0, OUTPUT);
  
  #ifdef SOFTAP
    WiFi.softAP(ssid, password);
    #ifdef DEBUGMODE
      IPAddress apip = WiFi.softAPIP(); // Get the IP server
      Serial.print("Connect your wifi laptop/mobile phone to this NodeMCU Access Point : ");
      Serial.println(ssid);
      Serial.print("Visit this IP : ");
      Serial.print(apip); // Prints the IP address of the server to be visited
      Serial.println(" in your browser.");
    #endif
  #endif

  #ifdef HOMENETWORK
    WiFi.begin(ssid, password);
    
    #ifdef DEBUGMODE
      while (WiFi.status() != WL_CONNECTED) {
        delay(1000);
        Serial.print(".");
      }
    
      Serial.println();
      Serial.print("Connect your wifi laptop/mobile phone with your local network: ");
      Serial.println(ssid);
      Serial.print("Visit this IP : ");
      Serial.println(WiFi.localIP());
      Serial.println(" in your browser.");
    #endif
  #endif
      
  server.on("/", response); 

  // Y Drive
  server.on("/Pos_Y", positiveYDrive);
  server.on("/Neg_Y", negativeYDrive);
  server.on("/SY", stopYDrive);

  // X Drive
  server.on("/Pos_X", positiveXDrive);
  server.on("/Neg_X", negativeXDrive);
  server.on("/SX", stopXDrive);

  // Cleaning
  server.on("/Start_Cleaning", startCleaning);
  server.on("/Stop_Cleaning", stopCleaning);

  //Fernwartung 
  server.on("/Start_FW", startFW);
  server.on("/Stop_FW", stopFW);

  // Start the server
  server.begin();
  #ifdef DEBUGMODE
    Serial.println("HTTP server beginned");
  #endif
}

void loop() {
  //Status LED, lights up when system ready
  digitalWrite(D0, LOW);

  noInterrupts();
  recieveData();
  interrupts();

  server.handleClient();
  sendDataToSerial();
}

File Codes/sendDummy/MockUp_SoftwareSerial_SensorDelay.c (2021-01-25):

#include "Arduino.h"
#include "SoftwareSerial.h"

SoftwareSerial mySerial(2, 3); // TX, RX

byte dataToSend[10] = {};
byte old_dataToSend[10] = {};
byte dataRecieve[6] = {};
byte bufferData[6] = {};
byte incomingSignal;
int OldState;

int count;

void sendDataTomySerial(){
  if(dataRecieve[0] == '0'){
    switch(count){      
    case 1:         
      dataToSend[0]= 'D'; 
      dataToSend[1]= 0;   
      dataToSend[2]= 0;   
      dataToSend[3]= 0;
      dataToSend[4]= 0;
      dataToSend[5]= 0;
      dataToSend[6]= 0;
      dataToSend[7]= 0;
      dataToSend[8]= 0;
      dataToSend[9]= 0;
      break;
    case 2:
      dataToSend[0]= 'H';
      dataToSend[1]= 0;
      dataToSend[2]= 1;
      dataToSend[3]= 0;
      dataToSend[4]= 0;
      dataToSend[5]= 1;
      dataToSend[6]= 0;
      dataToSend[7]= 0;
      dataToSend[8]= 0;
      dataToSend[9]= 0;
      break;
    case 3:
      dataToSend[0]= 'H';
      dataToSend[1]= 0;
      dataToSend[2]= 1;
      dataToSend[3]= 0;
      dataToSend[4]= 0;
      dataToSend[5]= 1;
      dataToSend[6]= 0;
      dataToSend[7]= 0;
      dataToSend[8]= 0;
      dataToSend[9]= 1;
      break;
    case 4:
      dataToSend[0]= 'J';
      dataToSend[1]= 0;
      dataToSend[2]= 0;
      dataToSend[3]= 0;
      dataToSend[4]= 1;
      dataToSend[5]= 0;
      dataToSend[6]= 0;     
      dataToSend[7]= 0;
      dataToSend[8]= 0;
      dataToSend[9]= 0;
      break;
    case 5:
      dataToSend[0]= 'J';
      dataToSend[1]= 0;
      dataToSend[2]= 0;
      dataToSend[3]= 0;
      dataToSend[4]= 1;
      dataToSend[5]= 0;
      dataToSend[6]= 1;     
      dataToSend[7]= 0;
      dataToSend[8]= 0;
      dataToSend[9]= 0;
      break;
    case 6:
      dataToSend[0]= 'F';
      dataToSend[1]= 1;
      dataToSend[2]= 0;
      dataToSend[3]= 0;
      dataToSend[4]= 0;
      dataToSend[5]= 1;
      dataToSend[6]= 0;     
      dataToSend[7]= 0;
      dataToSend[8]= 0;
      dataToSend[9]= 0;
      break;
    case 7:
      dataToSend[0]= 'F';
      dataToSend[1]= 1;
      dataToSend[2]= 0;
      dataToSend[3]= 0;
      dataToSend[4]= 0;
      dataToSend[5]= 1;
      dataToSend[6]= 0;     
      dataToSend[7]= 0;
      dataToSend[8]= 1;
      dataToSend[9]= 0;
      break;
    case 8:
      dataToSend[0]= 'I';
      dataToSend[1]= 0;
      dataToSend[2]= 0;
      dataToSend[3]= 1;
      dataToSend[4]= 0;
      dataToSend[5]= 0;
      dataToSend[6]= 0;     
      dataToSend[7]= 0;
      dataToSend[8]= 0;
      dataToSend[9]= 0;
      break;
    case 9:
      dataToSend[0]= 'I';
      dataToSend[1]= 0;
      dataToSend[2]= 0;
      dataToSend[3]= 1;
      dataToSend[4]= 0;
      dataToSend[5]= 0;
      dataToSend[6]= 0;     
      dataToSend[7]= 1;
      dataToSend[8]= 0;
      dataToSend[9]= 0;
      count = 0;
      break;
      default:
      break;
    }
  }else if(dataRecieve[0] == '1'){
    if(dataRecieve[3] == '1'){
      dataToSend[0]= 'E';
      dataToSend[1]= 0;
      dataToSend[2]= 0;
      dataToSend[3]= 0;
      dataToSend[4]= 1;
      dataToSend[6]= 1;     
      dataToSend[7]= 0;
      dataToSend[8]= 0;
      dataToSend[9]= 0;
    }else if(dataRecieve[4] == '1'){
      dataToSend[0]= 'D';
      dataToSend[1]= 0;
      dataToSend[2]= 0;
      dataToSend[3]= 1;
      dataToSend[4]= 0;
      dataToSend[6]= 0;     
      dataToSend[7]= 1;
      dataToSend[8]= 0;
      dataToSend[9]= 0;
    }else if(dataRecieve[1] == '1'){
      dataToSend[0]= 'B';
      dataToSend[1]= 1;
      dataToSend[2]= 0;
      dataToSend[3]= 0;
      dataToSend[4]= 0;
      dataToSend[6]= 0;     
      dataToSend[7]= 0;
      dataToSend[8]= 1;
      dataToSend[9]= 0;
    }else if(dataRecieve[2] == '1'){
      dataToSend[0]= 'C';
      dataToSend[1]= 0;
      dataToSend[2]= 1;
      dataToSend[3]= 0;
      dataToSend[4]= 0;
      dataToSend[6]= 0;     
      dataToSend[7]= 0;
      dataToSend[8]= 0;
      dataToSend[9]= 1;
    }else if(dataRecieve[5] == '1'){
      dataToSend[0]= 'F';
      dataToSend[1]= 0;
      dataToSend[2]= 0;
      dataToSend[3]= 0;
      dataToSend[4]= 0;
      dataToSend[5]= 1;
      dataToSend[6]= 0;     
      dataToSend[7]= 0;
      dataToSend[8]= 0;
      dataToSend[9]= 0;
    }
    else{
      dataToSend[0]= 'A';
      dataToSend[1]= 0;
      dataToSend[2]= 0;
      dataToSend[3]= 0;
      dataToSend[4]= 0;
      dataToSend[5]= 0;
      dataToSend[6]= 0;
      dataToSend[7]= 0;
      dataToSend[8]= 0;
      dataToSend[9]= 0;
    }                 
  }
  if(dataRecieve[0] == '0'){
    delay(2000);
    count++;
  }
    if (dataToSend[0] != old_dataToSend[0] || //sendet nur wenn sich irgendwas ändert
    dataToSend[1] != old_dataToSend[1] || 
    dataToSend[2] != old_dataToSend[2] ||
    dataToSend[3] != old_dataToSend[3] ||
    dataToSend[4] != old_dataToSend[4] ||
    dataToSend[5] != old_dataToSend[5] ||
    dataToSend[6] != old_dataToSend[6] ||
    dataToSend[7] != old_dataToSend[7] ||
    dataToSend[8] != old_dataToSend[8] ||
    dataToSend[9] != old_dataToSend[9]){ 
    for (int x = 0; x<10; x++){  
      mySerial.print(dataToSend[x]); 
    }
    for (int i = 0; i < 10; i++) {
      old_dataToSend[i] = dataToSend[i];
      } 
  }
}

void recieveDataFrommySerial(){
  mySerial.setTimeout(100);
  if(mySerial.available()){
    incomingSignal = mySerial.readBytes(bufferData, 6);
    for(int i = 0; i < 6; i++){
      dataRecieve[i] = bufferData[i];
      Serial.print(dataRecieve[i] - '0');
    }
    Serial.println("");
  }
}

void setup() {
  Serial.begin(9600);
  mySerial.begin(9600);
}

void loop() {
  sendDataTomySerial();
  recieveDataFrommySerial();
}

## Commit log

2021-01-05 arduino_codes hochgeladen
    [UART-Telegramm_Aufbau (1).xlsx]
2021-01-05 neue codes
    [UART-Telegramm_Aufbau (1).xlsx]
2021-01-14 add esp driver
2021-01-19 atoi war das Problem
    [main.cpp]
2021-01-19 Homenetwork und SoftAP ergänzt
2021-01-23 GUI mit seriellem Monitor des Mock-Ups
2021-01-24 Doku für das Gehäuse und den Hutschienen Adapter
    [ESP_Adapter.stp, case_bottom_v3.stl, case_top_v4.stl]
2021-01-25 SensorDelay final
